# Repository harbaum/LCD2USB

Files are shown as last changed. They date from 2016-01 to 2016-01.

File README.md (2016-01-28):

# LCD2USB

## Overview

LCD2USB is a open source/open hardware project. The goal of LCD2USB is to connect HD44780 based text LCD displays to various PCs via USB. LCD2USB was meant to be cheap and to be made of easily available parts. It is therefore based on the [Atmel AVR Mega8 CPU](http://www.atmel.com/dyn/products/product_card.asp?part_id=2004) and does not require any difficult to obtain parts like separate USB controllers and the like. The total cost (without display and pcb) are about 5 to 10 Euros. LCD2USB currently comes with a simple demo application that works under Linux, MacOS X and Windows.

LCD2USB is currently supported by [lcd4linux](http://ssl.bulix.org/projects/lcd4linux/) (LCD2USB support is built-in), [LCD Smartie](http://lcdsmartie.sourceforge.net/) (requires a [seperate driver](contrib/LCD2USB.dll)), and [LCDProc](http://lcdproc.org/) (LCD2USB support is built-in).

Every now and then i have spare PCBs available. Send me an email if you are interested.

LCD2USB makes use of several projects to achieve this goal. LCD2USB is based on:

*   [LCD4LINUX, a great framework to use small LCDs with linux](http://ssl.bulix.org/projects/lcd4linux/),
*   [AVR-USB, a pure software implementation of USB for the AVR plattform](http://www.obdev.at/products/avrusb/index.html),
*   [USBtiny, another software usb implementation for the AVR](http://www.xs4all.nl/~dicks/avr/usbtiny/), and
*   [Peter Fleurys LCD routines for the AVR](http://jump.to/fleury)

## Hardware

[](images/prototyp.jpg)

**The prototype board**

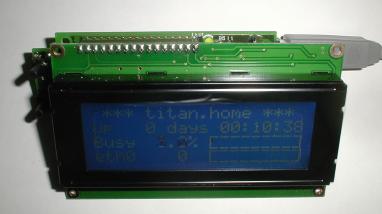
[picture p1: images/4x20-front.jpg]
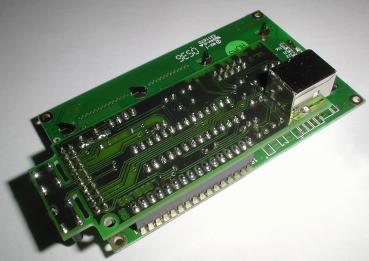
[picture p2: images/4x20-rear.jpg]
 | 
---- | ----
**The final pcb mounted on a 4x20 display** | **The USB connector is mounted on the rear PCB side**

The hardware of the LCD2USB interface consists of the [Atmel AVR Mega8 CPU](http://www.atmel.com/dyn/products/product_card.asp?part_id=2004), a cheap and easy to obtain microcontroller with 8 KBytes flash (of which ~3k are used in this application) and 2 KBytes RAM. The processor is surrounded by few parts, mainly connectors to interface to the PC and the LCD.



A power LED (LED1) indicates that the system is powered via USB. The system clock is derived from a 12Mhz crystal. This frequency is necessary due to the fact that the software USB implementation requires a precise timing with respect to the USB.

### The USB interface

The USB interface of the LCD2USB interface is based on a pure software implementation and uses three pins of the AVR (PC0, PC1 and PD2). This software implementation supports low speed USB only which is signalled to the PC by resistor R1\. The current version 1.1 of the LCD2USB operates the USB data lines at 3.6V which complies to the USB spec and increases compatibility over version 1.0.

The USB connection may be done via a USB B style connector. This is the square connector that is typically used for USB devices (unlike the flat A style connector used at USB hosts). The USB connector is to be **mounted at the solder side** (the rear side of the PCB without the white printing). Mounting it to the component side may damage the LCD2USB or even the PC when plugging it in. Alternally a cable may directly be attached to the component side of the board as depicted in the image below.

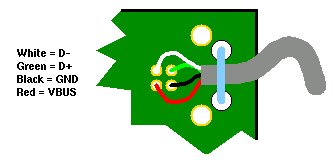
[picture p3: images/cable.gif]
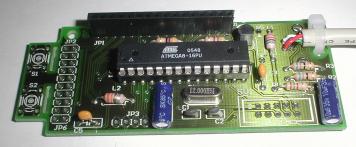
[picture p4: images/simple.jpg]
 | 
---- | ----
**Direct attachment of an USB cable** | **The minimum working setup for pre-flashed CPUs**

The whole device a so called bus powered device. This means that the complete device is powered directly from USB. Therefore the AVR and the LCD are powered from the USB VBUS signal. This signal can deliver max 500mA to a device. The power supply is filtered and buffered by C3 and C6.

### The LCD interface

The LCD2USB interface supports several different HD44780 based text displays. It supports single controller displays (tested with 16*2, 20*2 and 20*4) and dual controller displays (tested with 27*4 and 40*4). The LCD2USB interface uses the 4 bit interface provided by the HD44780.

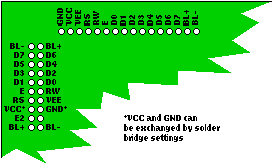
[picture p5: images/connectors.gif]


Two different connectors (JP1 and JP2) are present to interface to most common HD44780 displays. The extension connector JP6 expands JP2 for the dual controller display connectors as used on e.g. 40*4 displays. See figures for details. Since the power supply of the 40*4 connection varies from the 20*2 connector style, the solder bridges SJ2 and SJ3 allow to adjust the power supply polarity on JP2. The default setting is for the 20*2 style connection. The following image shows how to change the settings for a 4x40 display:

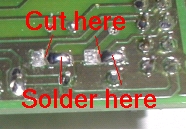
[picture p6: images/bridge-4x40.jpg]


**Warning:** Using the wrong polarity will most likely destroy the LCD, the interface and may even damage the PCs USB port. Please make sure, that the connector of the display matches the signal layout on the LCD2USB board. You might want to use a USB hub between the LCD2USB and your PC during the first trials. This lowers the risk of damanging the PC if you didn't get the LCD power supply correctly. However, you may still damage the LCD2USB, the LCD and your hub.

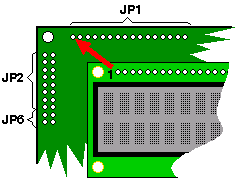
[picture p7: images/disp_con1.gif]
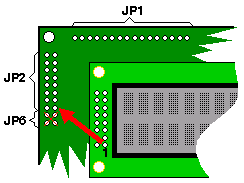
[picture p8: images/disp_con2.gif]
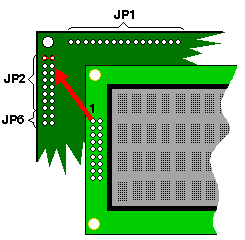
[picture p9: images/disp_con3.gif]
 |  | 
---- | ---- | ----
**Display: 2*16, 4*16, 4*20** | **Display: 2*20, 2*40** | **Display: 4*40 <font color="red">(adjust solder bridge!)</font>**

#### Power supply considerations

Special care has to be taken with displays with backlighting. The LCD2USB has been designed to draw at most 75mA which is fine for typical LCDs with LED backlighting. This value is also reported to the host PC via the USB configuration. The LCD2USB interface hardware is able to supply up to 100mA via its software adjustable backlight control. This is a limitation of the transistor T1\. If the backlighting draws more than 100mA, transistor T1 has to be replaced (see the section "part list remarks" below for more details) and special care has to be taken not to overload the USB which can source at most 500mA in total to a bus powered device. An increased backlight current should be reflected in the USB configuration of the device by adjusting the value of <tt>USB_CFG_MAX_BUS_POWER</tt> in the file <tt>usbconfig.h</tt> of the firmware sourcecode. You'll then have to recompile the firmware to make it signal its increased power consumption via USB. These firmware changes may not be necessary with all PCs but some may even shut down the power supply for a device that actually draws more current than its USB descriptors indicate.

### Programming interface (ISP)

The firmware is uploaded using the standard 10 pin AVR ISP connector (SV1). A separate programming cable is required to load the firmware onto the LCD2USB. A [simple do-it-yourself cable](images/avrisp.gif) will be sufficient. A PC software like e.g. [Ponyprog](http://www.lancos.com/prog.html) or [UISP](http://savannah.nongnu.org/projects/uisp/) will then be used to upload the firware via this cable to the AVR on the LCD2USB device. The programming cable is only required once, since the firmware is permanently stored in the AVRs internal flash memory.

### The serial interface

Connector JP3 provides the serial interface of the AVR. This connector is meant for debugging purposes only and must not be directly connected to a PCs RS232 interface. Instead a level shifter (e.g. MAX232) must be inserted.

### Schematics and pcb layout

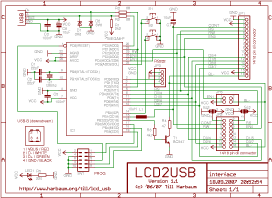
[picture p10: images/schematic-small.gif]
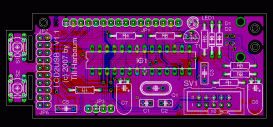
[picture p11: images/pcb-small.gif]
  

#### NEW: PCB version 1.1

The latest PCB version includes the two zener diodes to increase USB compatibility. Furthermore the power supply inductor has turned out not to be neccessary and has thus been removed to make space for the new zener diodes.

I sometimes have spare PCBs. Send me an email if you want to buy one of them.

### Part list

You can get all parts directly via the [lcd2usb part list at Reichelt](http://www.reichelt.de/?ACTION=20;AWKID=50388;PROVID=2084). This list is for the V1.1 pcb and includes the following parts:

Part | Qty | Name | [Reichelt Part No.](http://www.reichelt.de) | [Conrad Part No.](http://www.conrad.de)
---- | ---- | ---- | ---- | ----
Q1 | 1 | 12Mhz crystal, HC49U package | 12,0000-HC49U-S | 445167
R1 | 1 | 2.2k ohm resistor | 1/4W 2,2k | 403296
R2, R3 | 2 | 68 ohm resistor | 1/4W 68 | 403113
R4 | 1 | 47 ohm resistor | 1/4W 47 | 403091
R5 | 1 | 220 ohm resistor | 1/4W 220 | 403172
R6 | 1 | 4.7k ohm resistor | 1/4W 4,7k | 403334
C1, C2 | 2 | 22pF ceramic capacitor, 2.54mm | KERKO 22P | 457167
C3, C5 | 2 | 100nF capacitor, 5.08mm | X7R-5 100N | 453358
C6, C7 | 2 | 10μF electrolytic capacitor | RAD 10/35 | 472484
T1 | 1 | BC547C transistor | BC 547C | 154989
L1 | 1 | 10μH inductor | SMCC 10μ | 535729
S1, S2 | 2 | push button | TASTER 9305 | 700460
SV1 | 1 | 10 pin ISP connector | WSL 10G | 744026
JP1 | 1 | display connector | BL 1X20G 2,54 | 734993
JP2, JP6 | 1 | display connector | BL 2X10G 2,54 | 741159
-- | 1 | display side connector for JP2/JP6 | SL 2X10G 2,54 | 744026
JP3 | 1 | 4 pin debug connector, display side connector for JP1 | SL 1X36G 2,54 | 744018
LED1 | 1 | LED 3mm green | LED 3MM GN | 184713
-- | 1 | USB-B print connector | USB BW | 743950
IC1 | 1 | Atmega8-16 DIP | ATMEGA 8-16 DIP | 154054
-- | 1 | socket for IC1 | GS 28P-S | 189515
D1, D2 | 2 | 3.6V zener diode | ZF 3,6 | 180050

Additionally required: Display, USB cable

#### Part list remarks

The crystal should be in the small HC49U package. You can use a crystal in HC18 package, but you'd then have to mount it from the rear pcb side.

C1 and C2 should have their pins 2.54mm (1/10 inch) apart, C3 and C5 have their pins 5.08mm (2/10 inch) apart.

Although T1 is labeled BC547C, a BC547A or BC547B will be fine as well.

The cathode of LED1 faces the R5 label. The long leg of the LED is thus close to JP1.

Resistor R4 is the current limiting resistor for backlighting. The 47 ohm in the part list is a useful and secure value for some LCDs with low power LED backlighting. Some displays already include the current limiting resistor and/or require a higher current. The symptom usually is a very dark or even barely visible backlighting with R4 at 47 ohms. You can lower the value of R4 in order to increase the backlight current and thus the brightness. Please consult the datasheet of your display for its backlight power requirements and in order to select the correct current limiting resistors. The BC547 transistor T1 may not be sufficient for displays requiring backlight currents > 100mA. A user has reported success by replacing T1 with a BS170 MOSFET and driving the backlight with 240mA.

## Uploading the firmware

If you are familiar with Atmel programming you probably know what you are doing. The Makefile in lcd2usb/firmware/Makefile assumes, that you are using a [simple stk200 compatible printer port adapter](images/avrisp.gif). This is e.g. the same one as sold by [emedia](http://www.emedia.de) for the BlueMP3 device.

Connect the assembled device (no display required yet) via USB to the PC. It will not be detected yet, since it doesn't contain the firmware. Connect it via the download cable and the programming adapter to the linux pc with installed [uisp tool](http://savannah.nongnu.org/projects/uisp/) and type "make fuse; make flash-nodep" to upload the firmware.

If the Makefile doesn't work for you you can also flash the device manually using [avrdude](http://www.nongnu.org/avrdude/) and the aforementioned stk200 compatible printer port adapter with the following parameters:

<pre>avrdude -c stk200 -p atmega8 -U lfuse:w:0x9f:m -U hfuse:w:0xc9:m -U flash:w:firmware-avrusb.hex
</pre>

As of LCD2USB version 1.4, download via usb with the [USBasp tool](http://www.fischl.de/usbasp/) using [avrdude](http://www.nongnu.org/avrdude/) is supported as well. Type "make avrdude-nodep" to upload the firmware this way.

To manually upload the firmware using the [usbasp](http://www.fischl.de/usbasp/) just use the follwing command:

<pre>avrdude -c usbasp -p atmega8 -U lfuse:w:0x9f:m -U hfuse:w:0xc9:m -U flash:w:firmware-avrusb.hex
</pre>

If your are familiar with a different AVR programming system you can of course use that one as well. But you'll probably have to do some minor adjustments in the Makefile.

## Protocol description

For simplicity reasons, the LCD2USB interface only uses USB control messages. More efficient and faster bulk transfers are only available to high speed devices. A USB control message for a low speed device consists of exactly 8 Bytes. The first byte indicates the control type and has to be set to a fixed value for vendor specific commands like the LCD2USB is using for its own purposes (non vendor specific commands are e.g. used to request the device name and id etc). The remaining seven bytes are the request type (1 byte), a value (2 bytes), an index (2 bytes) and a length field (2 bytes) for data being transmitted with the control transfer. The LCD2USB protocol does not send extra data, thus the last two bytes should be 0 for compatibility reasons. The remaining four bytes (two bytes value and two bytes index) are left for the data transfer. These are used to transmit up to four data bytes per transfer. Four HD44780 command bytes or four HD44780 data bytes can thus be transferred during one USB transaction.

### Details for the request byte

<pre>Bit   7 6 5 4 3 2 1 0
Name  C C C T T R L L
</pre>

<pre>CCC = command type
  0 (000) = echo
  1 (001) = command
  2 (010) = data
  3 (011) = set
  4 (100) = get
  5 (101) = reserved for future use
  6 (110) = reserved for future use
  7 (111) = reserved for future use
</pre>

<pre>TT = target id
R = reserved for future use, set to 0
LL = number of bytes in transfer - 1
</pre>

The target id has different meaning for the different requests. For command and data transfers it is a two bit bitmap indicating which of the two possible controllers supported by the LCD2USB interface is addressed. Both controllers may be addressed at the same time (e.g. to setup user defined characters).

For set and get operations the target id specifies the value to set or get. Currently supported values are:

<pre>set 0 - set brightness
set 1 - set contrast
get 0 - get firmware version (msb = major version, lsb = minor version)
get 1 - get button bitmap
get 2 - get detected controllers
</pre>

See the testapp source code delivered with the LCD2USB firmware archive for further details.

## Software

The LCD2USB interface was originally developed for use with [lcd4linux](http://ssl.bulix.org/projects/lcd4linux/). In the meantime [LCD Smartie](http://lcdsmartie.sourceforge.net/) and [LCDProc](http://lcdproc.org/) have been extended to support the LCD2USB as well. The LCD2USB software archives contain a little demo application that can be used as a basis for further LCD2USB ports. Currently Linux, MacOS X and Windows are supported by this application.

### Using LCD2USB under Windows

Harald Körfgen wrote a LCD Smartie plugin for LCD2USB finally allowing the LCD2USB to be used under Windows as well. Here's what he writes about his plugin:

[LCD2USB-smartie.zip](contrib/LCD2USB-smartie.zip) contains all the necessary source files requried to compile the driver with Microsoft ® Windows Server® 2003 R2 Platform SDK, Microsoft Visual C++ 2005 Express Edition and LibUsb-Win32\. [LCD2USB.dll](contrib/LCD2USB.dll) is the resulting file.

In order to use the driver libusb-win32 has also to be installed and the [LCD2USB.dll](contrib/LCD2USB.dll) has to be placed in the "displays" directory of LCD Smartie and it will be auto-detected and automatically be used. He has only tested his driver with a 20x4 display yet, so feedback is welcome.

## Troubleshooting

Problem: The device seems to work fine, it is detected correctly by Linux, but i get various error messages when accessing it from the test application.

Solution: Make sure that you run the test application as the root user since the standard user may lack the rights to access all aspects of the lcd2usb hardware.

Problem: The device is not properly detected. Linux reports an error like "device not accepting address" in the system log but the LCD displays the init message (LCD2USB VXX.XX).

Solution: The USB interface is not working at all. Your AVR is very likely running at the wrong speed. Please make sure that the fuses are set correctly. If this doesn't help, the zener diodes may be too slow (see next problem).

Problem: The device is not properly detected. Linux reports an an error like "device descriptor read/all, error -71" in the system log.

Solution: The device is working partly and the USB transfers are unreliable. This was often caused by "slow" high current zener diodes which i had on the Reichelt part list some time ago. These slow diodes are easily recognized as they have thicker wires than the other parts. You can just try to remove the zener diodes and the device will work if your host PC copes with 5V on the USB data lines (most PCs do, especially older ones). Also using a USB hub between a device without zener diodes and the PC may lead to a working setup even if the PC does not accept 5V on the USB data lines. Otherwise you need faster diodes as a replacement like the one available from reichelt under part no "ZF 3,6". These are also part of the current part list and are known to work.

## Links

*   [LCD4LINUX, lcd interfacing for linux](http://ssl.bulix.org/projects/lcd4linux/)
*   [AVR-USB, software USB for the AVR plattform](http://www.obdev.at/products/avrusb/index.html)
*   [USBtiny, another software usb implementation for the AVR](http://www.xs4all.nl/~dicks/avr/usbtiny/)
*   [LCD routines for the AVR plattform](http://jump.to/fleury)
*   [USB user space library libusb](http://libusb.sourceforge.net/)
*   [Win32 port of libusb](http://libusb-win32.sourceforge.net/)
*   [LCD Smartie, the Windows pendant of lcd4linux](http://lcdsmartie.sourceforge.net/)
*   [Later version of LCDproc include LCD2USB support](http://lcdproc.org/)

## User contributions

*   [Gallery of LCD2USB assembly](http://gallery.port23.de/v/bastard/wrap/lcd/?g2_page=4&g2_navId=x4b94fc39)
*   [Support for 12 button matrix keyboard on lcd2usb](http://lists.omnipotent.net/pipermail/lcdproc/2010-February/013267.html)

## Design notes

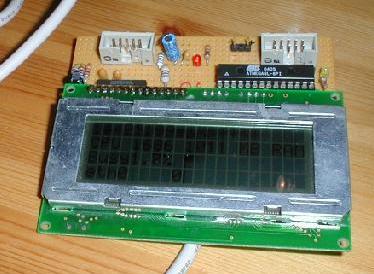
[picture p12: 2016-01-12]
images/prototyp.jpg

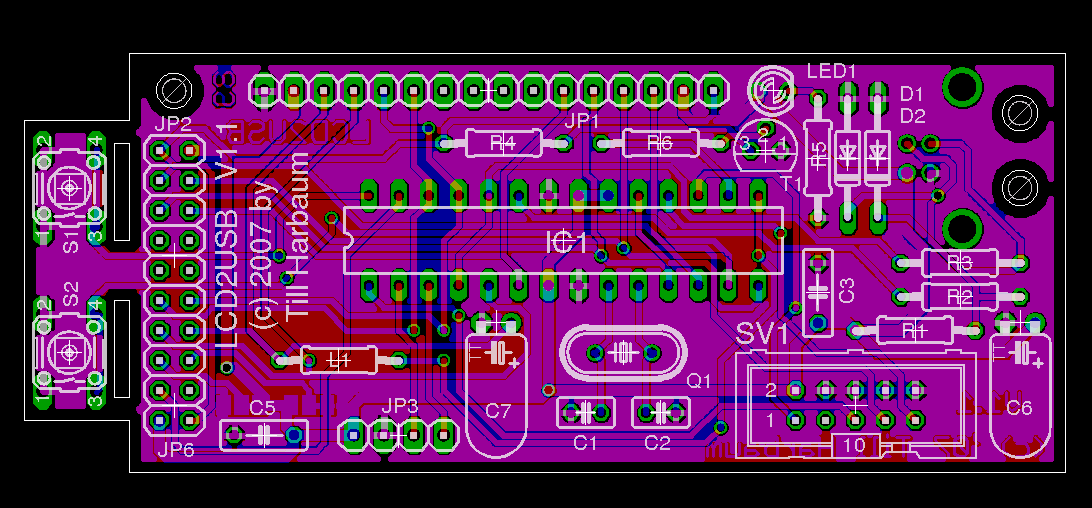
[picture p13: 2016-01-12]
images/pcb.gif

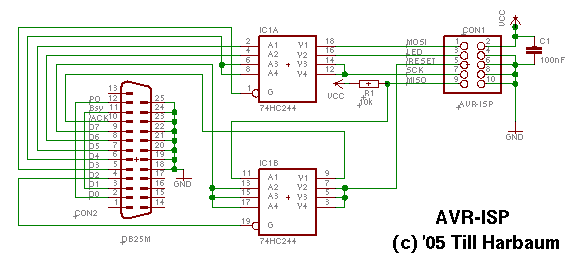
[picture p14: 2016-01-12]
images/avrisp.gif

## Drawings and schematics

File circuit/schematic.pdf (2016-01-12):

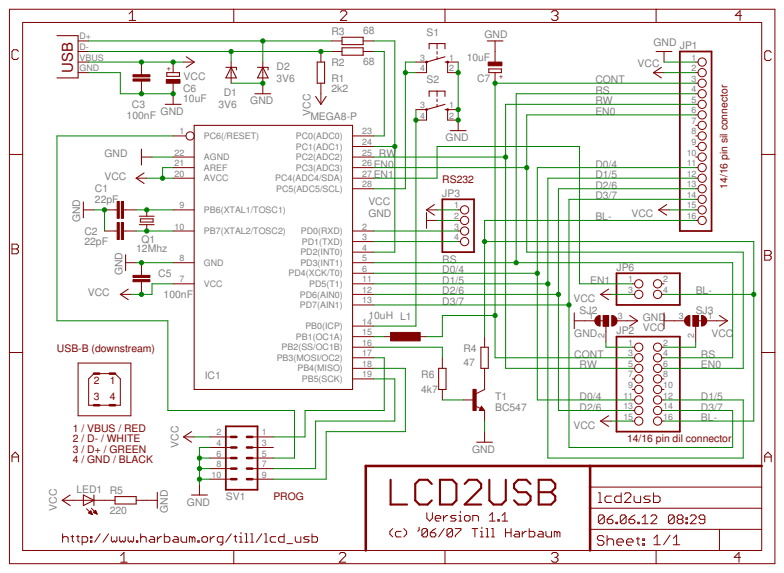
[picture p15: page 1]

D2/6
D3/7

14/16 pin dil connector PROG

10 | 9

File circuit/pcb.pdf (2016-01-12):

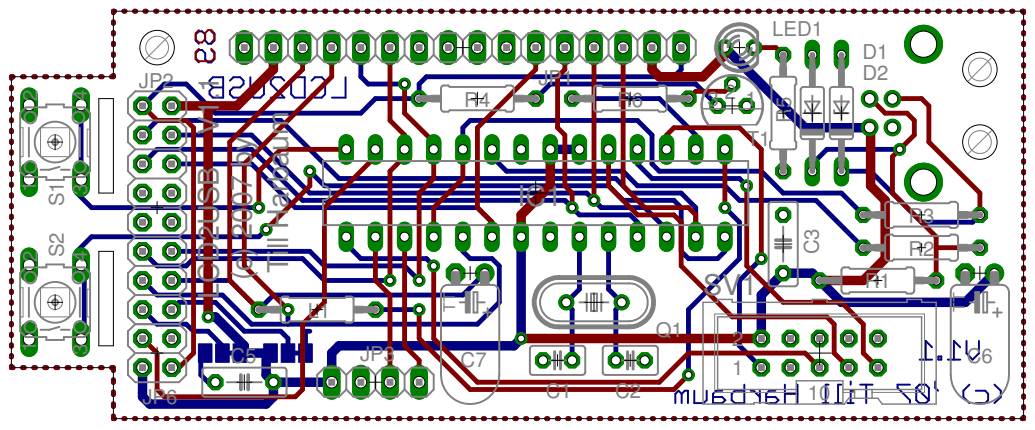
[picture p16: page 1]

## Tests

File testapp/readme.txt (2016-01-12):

lcd2usb test application  -  http://www.harbaum.org/till/lcd2usb
----------------------------------------------------------------

This simple test application is meant to demonstrate libusb
interfacing to the lcd2usb interface.

This is no useful application, if you are only interesting in 
using the lcd2usb interface please check out the latest version 
of lcd4linux. 

Linux
-----

This demo application has been developed under and for linux. Just
make sure you have libusb installed. To use this program just
compile by typing "make" and run the resulting lcd2usb.

Windows
-------

This program can be compiled for windows. This has been tested 
under Linux using xmingw and the windows port of libusb 
(see http://libusb-win32.sourceforge.net). To install the 
driver plug the device in and install the driver from
the win directory. Then run testapp/lcd2usb.exe

This program may also be compiled under windows using cygwin or
mingw (which is part of cygwin). In order to use cygwin simply 
copy usb.h win32-linusb to /cygwin/usr/include and libusb.a to
/cygwin/lib and do a "make -f Makefile.cygwin". Don't forget to 
distribute /cygwin/bin/cygwin1.dll with your file to allow it to 
run in non-cygwin environments as well. No dll is required when using 
mingw. In that case copy usb.h to /cygwin/usr/include/mingw and 
libusb.a to /cygwin/lib/mingw. Finally do a "make -f Makefile.mingw".

MacOS X
-------

The program can be compiled under MacOS as well. The fink version
of linusb has to be installed and a simple "make -f Makefile.macos"
will build the native MacOS X version.

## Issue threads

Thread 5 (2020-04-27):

Cound not find LCD2USB device

knoesterpitter, 2020-04-27:
I would be happy, if I get the software running.
My Environment:
Raspberry Pi Model B Rev 2
Linux rasp1-buster 4.19.97+ #1294 Thu Jan 30 13:10:54 GMT 2020 armv6l GNU/Linux
I did:
sudo pip install lcd2usb
Looking in indexes: https://pypi.org/simple, https://www.piwheels.org/simple
Requirement already satisfied: lcd2usb in /usr/local/lib/python2.7/dist-packages (1.2)
Requirement already satisfied: libusb1 in /usr/local/lib/python2.7/dist-packages (from lcd2usb) (1.7.1)

Now the 1602 RGB LCD is connected with the USB-Port

sudo python usblcd.py
Traceback (most recent call last):
  File "usblcd.py", line 9, in <module>
    lcd = LCD()
  File "/usr/local/lib/python2.7/dist-packages/lcd2usb.py", line 69, in __init__
    raise LCD2USBNotFound()
lcd2usb.LCD2USBNotFound: Cound not find LCD2USB device.

I am shure its my fault. But I dont know where to look.
I hope, somebody has a soultion or a hint (or a URL).
Many thanks in advance.

ConiKost, 2023-05-08:
Well, does you kernel has the needed modules, so your lcd module will show up as lcd device? What does ```lsusb``` show?

BlackMage2, 2023-07-01:
I also have a lcd2usb device that doesn't work. it is also not listed in lsusb. probably a defective controller I would say

ConiKost, 2023-07-01:
Yeah, sound so. It should be listed at least in lsusb.

harbaum, 2023-07-02:
Does the display itself show any signs of life? It should at least power up when connected to USB.

BlackMage2, 2023-07-02:
yes, in display is shown "LCD2USB V1.09"

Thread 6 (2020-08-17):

How to adapt to atmega 328p?

CelsoCaldeira, 2020-08-17:
would it be possible to adapt this project to run with an atmega328p? more specifically with an arduino pro micro/mini?
how hard could it be to do this?
I know the clock is different so some changes might need to be made...
the pcb would need to be redesigned i know this too.
thanks for any helpful info!

plazmax, 2023-11-20:
Were you able to adapt it to ATMEGA 328P? Atmega 328p is backwards compatible, it can run the code written for Atmega 8, the pins look exactly the same, I need to burn the code and try it.

plazmax, 2023-11-20:
> would it be possible to adapt this project to run with an atmega328p? more specifically with an arduino pro micro/mini? how hard could it be to do this? I know the clock is different so some changes might need to be made... the pcb would need to be redesigned i know this too. thanks for any helpful info!

Were you able to adapt it to ATMEGA 328P? Atmega 328p is backwards compatible, it can run the code written for Atmega 8, the pins look exactly the same, I need to burn the code and try it.

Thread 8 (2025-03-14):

can,t open .brd file

sulintang, 2025-03-14:
can,t open .brd file

harbaum, 2025-03-14:
This has been made with a very old eagle version. I cannot tell you which software will read that today.

daduke, 2025-04-11:
KiCad worked fine ~ a year ago

sulintang, 2025-04-11:
> This has been made with a very old eagle version. I cannot tell you which software will read that today.

thank you

sulintang, 2025-04-11:
> KiCad worked fine ~ a year ago

i use 6.0 not working

daduke, 2025-04-13:
don't ask me how I did it at the time (it was 2.5y ago...), but here's the KiCad + jlcpcb gerber: https://daduke.org/junk/lcd2usb.tgz

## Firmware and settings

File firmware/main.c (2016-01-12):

/* Name: main.c
 * Project: LCD2USB; lcd display interface based on AVR USB driver
 * Author: Till Harbaum
 * Creation Date: 2006-01-20
 * Tabsize: 4
 * Copyright: (c) 2005 by Till Harbaum <till@harbaum.org>
 * License: GPL
 * This Revision: $Id: main.c,v 1.2 2007/01/14 12:12:27 harbaum Exp $
 */

#include <avr/io.h>
#include <avr/interrupt.h>
#include <avr/pgmspace.h>
#include <avr/wdt.h>
#include <avr/eeprom.h>

#include <util/delay.h>

#include "lcd.h"

// use avrusb library
#include "usbdrv.h"
#include "oddebug.h"

#define VERSION_MAJOR 1
#define VERSION_MINOR 9
#define VERSION_STR "1.09"
// change USB_CFG_DEVICE_VERSION in usbconfig.h as well

// EEMEM wird bei aktuellen Versionen der avr-lib in eeprom.h definiert
// hier: definiere falls noch nicht bekannt ("alte" avr-libc)
#ifndef EEMEM
// alle Textstellen EEMEM im Quellcode durch __attribute__ ... ersetzen
#define EEMEM  __attribute__ ((section (".eeprom")))
#endif
 
/* bitmask of detected lcd controllers */
uchar controller = 0;

/* ------------------------------------------------------------------------- */
/* PWM units are used for contrast and backlight brightness */

/* contrast and brightness are stored in eeprom */
uchar eeprom_valid EEMEM;
uchar eeprom_contrast EEMEM;
uchar eeprom_brightness EEMEM;

void pwm_init(void) {

  /* check if eeprom is valid and set default values if not */
  /* initial values: full contrast and full brightness */
  if(eeprom_read_byte(&eeprom_valid) != 0x42) {

    /* write magic "eeprom is valid" marker 0x42 and default values */
    eeprom_write_byte(&eeprom_valid, 0x42);
    eeprom_write_byte(&eeprom_contrast, 0xff);
    eeprom_write_byte(&eeprom_brightness, 0xff);
  }

  /* PortB: set DDB1 and DDB2 => PORTB1 and PORTB2 are output */
  DDRB |= _BV(1) | _BV(2);
 
  /* Set Timer1:
    - Fast PWM,8bit => Mode 5 (WGM13=0,WGM12=1,WGM11=0,WGM10=1)
    - Output-Mode: lower voltage is higher contrast
      => Set OC1A on Compare Match, clear OC1A at BOTTOM, (inverting mode)
	 COM1A1=1,COM1A0=1
	 higher voltage is higher brightness
      => Clear OC1B on Compare Match, set OC1B at BOTTOM, (non-inverting mode)
	 COM1B1=1,COM1B0=0
    - Timer runs at inernal clock with no prescaling => CS12=0,CS11=0,CS10=1
  */
  TCCR1A = _BV(COM1A1) | _BV(COM1A0) | _BV(COM1B1) | _BV(WGM10);
  TCCR1B = _BV(WGM12) | _BV(CS10);

  TIMSK &=( (~_BV(2)) & (~_BV(3)) & (~_BV(4)) & (~_BV(5)));

  OCR1A = eeprom_read_byte(&eeprom_contrast);
  OCR1B = eeprom_read_byte(&eeprom_brightness);
}

void set_contrast(uchar value) {
  /* store value in eeprom if it actually changed */
  if(value != eeprom_read_byte(&eeprom_contrast))
    eeprom_write_byte(&eeprom_contrast, value);

  OCR1A = value;  // lower voltage is higher contrast
}

void set_brightness(uchar value) {
  /* store value in eeprom if it actually changed */
  if(value != eeprom_read_byte(&eeprom_brightness))
    eeprom_write_byte(&eeprom_brightness, value);

  OCR1B = value;  // higher voltage is higher brightness
}

/* ------------------------------------------------------------------------- */

uchar	usbFunctionSetup(uchar data[8]) {
  static uchar replyBuf[4];
  usbMsgPtr = replyBuf;
  uchar len = (data[1] & 3)+1;       // 1 .. 4 bytes 
  uchar target = (data[1] >> 3) & 3; // target 0 .. 3
  uchar i;

  // request byte:

  // 7 6 5 4 3 2 1 0
  // C C C T T R L L

  // TT = target bit map 
  // R = reserved for future use, set to 0
  // LL = number of bytes in transfer - 1 

  switch(data[1] >> 5) {

  case 0: // echo (for transfer reliability testing)
    replyBuf[0] = data[2];
    replyBuf[1] = data[3];
    return 2;
    break;
    
  case 1: // command
    target &= controller;  // mask installed controllers

    if(target) // at least one controller should be used ...
      for(i=0;i<len;i++)
	lcd_command(target, data[2+i]);
    break;

  case 2: // data
    target &= controller;  // mask installed controllers

    if(target) // at least one controller should be used ...
      for(i=0;i<len;i++)
	lcd_data(target, data[2+i]);
    break;

  case 3: // set
    switch(target) {

    case 0:  // contrast
      set_contrast(data[2]);
      break;

    case 1:  // brightness
      set_brightness(data[2]);
      break;

    default:
      // must not happen ...
      break;      
    }
    break;

  case 4: // get
    switch(target) {
    case 0: // version
      replyBuf[0] = VERSION_MAJOR;
      replyBuf[1] = VERSION_MINOR;
      return 2;
      break;

    case 1: // keys
      replyBuf[0] = ((PINC & _BV(5))?0:1) | 
	            ((PINB & _BV(0))?0:2);
      replyBuf[1] = 0;
      return 2;
      break;

    case 2: // controller map
      replyBuf[0] = controller;
      replyBuf[1] = 0;
      return 2;
      break;      

    default:
      // must not happen ...
      break;      
    }
    break;

  default:
    // must not happen ...
    break;
  }

  return 0;  // reply len
}

/* ------------------------------------------------------------------------- */

int	main(void) {
  wdt_enable(WDTO_1S);

  /* let debug routines init the uart if they want to */
  odDebugInit();

  /* all outputs except INT0 and RxD/TxD */
  DDRD = ~(_BV(2) | _BV(1) | _BV(0));  
  PORTD = 0;
  PORTC = 0;		   /* no pullups on USB pins */
  DDRC = ~0;		   /* output SE0 for USB reset */

  /* USB Reset by device only required on Watchdog Reset */
  _delay_loop_2(40000);   // 10ms

  DDRC = ~USBMASK;	   /* all outputs except USB data */
  usbInit();

  pwm_init();

  DDRC &= ~_BV(5);         /* input S1 */
  PORTC |= _BV(5);         /* with pullup */
  DDRB &= ~_BV(0);         /* input S2 */
  PORTB |= _BV(0);         /* with pullup */

  /* try to init two controllers */
  if(lcd_init(LCD_CTRL_0)) controller |= LCD_CTRL_0;
  if(lcd_init(LCD_CTRL_1)) controller |= LCD_CTRL_1;

  /* put string to display (line 1) with linefeed */
  if(controller & LCD_CTRL_0)
    lcd_puts(LCD_CTRL_0, "LCD2USB V" VERSION_STR);

  if(controller & LCD_CTRL_1)
    lcd_puts(LCD_CTRL_1, "2nd ctrl");

  if((controller & LCD_CTRL_0) && (controller & LCD_CTRL_1))
    lcd_puts(LCD_CTRL_0 | LCD_CTRL_1, " both!");

  sei();
  for(;;) {	/* main event loop */
    wdt_reset();
    usbPoll();
  }
  return 0;
}

/* ------------------------------------------------------------------------- */

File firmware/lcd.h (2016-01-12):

#ifndef LCD_H
#define LCD_H
/*************************************************************************
 Title	:   C include file for the HD44780U LCD library (lcd.c)
 Author:    Peter Fleury <pfleury@gmx.ch>  http://jump.to/fleury
 File:	    $Id: lcd.h,v 1.1.1.1 2007/01/14 11:37:56 harbaum Exp $
 Software:  AVR-GCC 3.3
 Hardware:  any AVR device, memory mapped mode only for AT90S4414/8515/Mega
***************************************************************************/

/**
 @defgroup pfleury_lcd LCD library
 @code #include <lcd.h> @endcode
 
 @brief Basic routines for interfacing a HD44780U-based text LCD display

 Originally based on Volker Oth's LCD library,
 changed lcd_init(), added additional constants for lcd_command(), 
 added 4-bit I/O mode, improved and optimized code.
       
 Memory mapped mode compatible with Kanda STK200, but supports also 
 generation of R/W signal through A8 address line.
       
 @author Peter Fleury pfleury@gmx.ch http://jump.to/fleury
 
 @see The chapter <a href="http://homepage.sunrise.ch/mysunrise/peterfleury/avr-lcd44780.html" target="_blank">Interfacing a HD44780 Based LCD to an AVR</a>
      on my home page.

*/

/*@{*/

#if (__GNUC__ * 100 + __GNUC_MINOR__) < 303
#error "This library requires AVR-GCC 3.3 or later, update to newer AVR-GCC compiler !"
#endif

#include <inttypes.h>
#include <avr/pgmspace.h>

/** 
 *  @name  Definitions for MCU Clock Frequency
 *  Adapt the MCU clock frequency in Hz to your target. 
 */
#define XTAL 12000000              /**< clock frequency in Hz, used to calculate delay timer */

/**
 *  @name Definitions for 4-bit IO mode
 *  Change LCD_PORT if you want to use a different port for the LCD pins.
 *
 *  The four LCD data lines and the three control lines RS, RW, E can be on the 
 *  same port or on different ports. 
 *  Change LCD_RS_PORT, LCD_RW_PORT, LCD_E_PORT if you want the control lines on
 *  different ports. 
 *
 *  Normally the four data lines should be mapped to bit 0..3 on one port, but it
 *  is possible to connect these data lines in different order or even on different
 *  ports by adapting the LCD_DATAx_PORT and LCD_DATAx_PIN definitions.
 *  
 */
#define LCD_DATA_PORT    PORTD        /**< port for the LCD lines   */
#define LCD_RS_PORT      PORTD        /**< port for RS line         */
#define LCD_RS_PIN       3            /**< pin  for RS line         */
#define LCD_RW_PORT      PORTC        /**< port for RW line         */
#define LCD_RW_PIN       2            /**< pin  for RW line         */
#define LCD_E_PORT       PORTC        /**< port for Enable line     */
#define LCD_E0_PIN       3            /**< pin  for Enable line 0   */
#define LCD_E1_PIN       4            /**< pin  for Enable line 1   */

#define LCD_CTRL_0       (1<<0)
#define LCD_CTRL_1       (1<<1)

/**
 *  @name Definitions for LCD command instructions
 *  The constants define the various LCD controller instructions which can be passed to the 
 *  function lcd_command(), see HD44780 data sheet for a complete description.
 */

/* instruction register bit positions, see HD44780U data sheet */
#define LCD_CLR               0      /* DB0: clear display                  */
#define LCD_HOME              1      /* DB1: return to home position        */
#define LCD_ENTRY_MODE        2      /* DB2: set entry mode                 */
#define LCD_ENTRY_INC         1      /*   DB1: 1=increment, 0=decrement     */
#define LCD_ENTRY_SHIFT       0      /*   DB2: 1=display shift on           */
#define LCD_ON                3      /* DB3: turn lcd/cursor on             */
#define LCD_ON_DISPLAY        2      /*   DB2: turn display on              */
#define LCD_ON_CURSOR         1      /*   DB1: turn cursor on               */
#define LCD_ON_BLINK          0      /*     DB0: blinking cursor ?          */
#define LCD_MOVE              4      /* DB4: move cursor/display            */
#define LCD_MOVE_DISP         3      /*   DB3: move display (0-> cursor) ?  */
#define LCD_MOVE_RIGHT        2      /*   DB2: move right (0-> left) ?      */
#define LCD_FUNCTION          5      /* DB5: function set                   */
#define LCD_FUNCTION_8BIT     4      /*   DB4: set 8BIT mode (0->4BIT mode) */
#define LCD_FUNCTION_2LINES   3      /*   DB3: two lines (0->one line)      */
#define LCD_FUNCTION_10DOTS   2      /*   DB2: 5x10 font (0->5x7 font)      */
#define LCD_CGRAM             6      /* DB6: set CG RAM address             */
#define LCD_DDRAM             7      /* DB7: set DD RAM address             */
#define LCD_BUSY              7      /* DB7: LCD is busy                    */

/* set entry mode: display shift on/off, dec/inc cursor move direction */
#define LCD_ENTRY_DEC            0x04   /* display shift off, dec cursor move dir */
#define LCD_ENTRY_DEC_SHIFT      0x05   /* display shift on,  dec cursor move dir */
#define LCD_ENTRY_INC_           0x06   /* display shift off, inc cursor move dir */
#define LCD_ENTRY_INC_SHIFT      0x07   /* display shift on,  inc cursor move dir */

/* display on/off, cursor on/off, blinking char at cursor position */
#define LCD_DISP_OFF             0x08   /* display off                            */
#define LCD_DISP_ON              0x0C   /* display on, cursor off                 */
#define LCD_DISP_ON_BLINK        0x0D   /* display on, cursor off, blink char     */
#define LCD_DISP_ON_CURSOR       0x0E   /* display on, cursor on                  */
#define LCD_DISP_ON_CURSOR_BLINK 0x0F   /* display on, cursor on, blink char      */

/* move cursor/shift display */
#define LCD_MOVE_CURSOR_LEFT     0x10   /* move cursor left  (decrement)          */
#define LCD_MOVE_CURSOR_RIGHT    0x14   /* move cursor right (increment)          */
#define LCD_MOVE_DISP_LEFT       0x18   /* shift display left                     */
#define LCD_MOVE_DISP_RIGHT      0x1C   /* shift display right                    */

/* function set: set interface data length and number of display lines */
#define LCD_FUNCTION_4BIT_1LINE  0x20   /* 4-bit interface, single line, 5x7 dots */
#define LCD_FUNCTION_4BIT_2LINES 0x28   /* 4-bit interface, dual line,   5x7 dots */
#define LCD_FUNCTION_8BIT_1LINE  0x30   /* 8-bit interface, single line, 5x7 dots */
#define LCD_FUNCTION_8BIT_2LINES 0x38   /* 8-bit interface, dual line,   5x7 dots */


#define LCD_MODE_DEFAULT     ((1<<LCD_ENTRY_MODE) | (1<<LCD_ENTRY_INC) )



/** 
 *  @name Functions
 */


/**
 @brief    Initialize display and select type of cursor
 @param    dispAttr \b LCD_DISP_OFF display off\n
                    \b LCD_DISP_ON display on, cursor off\n
                    \b LCD_DISP_ON_CURSOR display on, cursor on\n
                    \b LCD_DISP_ON_CURSOR_BLINK display on, cursor on flashing             
 @return  0 on failure, 1 on success
*/
extern uint8_t lcd_init(uint8_t ctrl);
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
